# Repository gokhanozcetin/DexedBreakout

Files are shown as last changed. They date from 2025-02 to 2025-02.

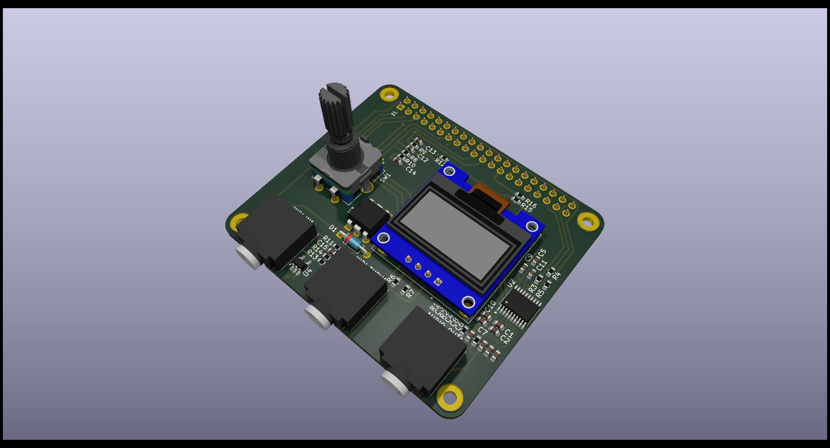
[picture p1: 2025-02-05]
dexedbreakout.png

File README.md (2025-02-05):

DexedBreakout is a small Raspberry Pi Hat that fits into of the shelf RPI cases with small modifications. The connections are aligned to RPI connectors so that the assmebly can be enclosed easily.

It includes a PCM5102 DAC, a 0.96 inch OLED and a rotary encoder. The PCB is arranged so that the OLED centers the Raspberry. It offers TRS type MIDI IN, a true hardware TRS type MIDI THRU and a stereo audio output jack.

The MIDI IN is connected to RX pin of the Raspberry PI I/O. MIDI THRU port replicates the MIDI IN signal via a buffer chip.

PCM5102 is configured to run in I2S mode and configuration pins are hardwired.

The Encoder is KY-040 type encoder. A/CLK is connected to GPIO9, B/DAT is connected to GPIO10 and switch is connected to GPIO11.

The 40 pin I/O header is designed to be a female regular input. A passthrough type would be much nicer to lower the position of the card however neither SMT nor THT pass-through connectors fit since the I/O is very close to the edge. It is possible not to populate the female header and directly solder the card to the RPI to lower the height and fit the assembly in to a case.

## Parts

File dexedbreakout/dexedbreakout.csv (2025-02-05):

Reference | Value | Datasheet | Footprint | Qty | DNP
AUDIO_OUT1;MIDI_IN1;MIDI_THRU1 | AudioJack3_SwitchTR | ~ | Connector_Audio:Jack_3.5mm_CUI_SJ1-3525N_Horizontal | 3
C1;C2;C3;C4;C5;C6;C7 | 2.2u | ~ | Capacitor_SMD:C_0603_1608Metric | 7
C8;C9;C10;C11;C15 | 0.1u | ~ | Capacitor_SMD:C_0603_1608Metric | 5
C12;C13;C14 | 10n | ~ | Capacitor_SMD:C_0603_1608Metric | 3
D1 | 1N4148 | https://assets.nexperia.com/documents/data-sheet/1N4148_1N4448.pdf | Diode_THT:D_DO-35_SOD27_P7.62mm_Horizontal | 1
J1 | Raspberry_Pi_2_3 | https://www.raspberrypi.org/documentation/hardware/raspberrypi/schematics/rpi_SCH_3bplus_1p0_reduced.pdf | Connector_PinSocket_2.54mm:PinSocket_2x20_P2.54mm_Vertical | 1
R1;R2;R12 | 470 | ~ | Resistor_SMD:R_0603_1608Metric | 3
R3;R4;R5 | 22 | ~ | Resistor_SMD:R_0603_1608Metric | 3
R6;R7;R8;R9;R10 | 4k7 | ~ | Resistor_SMD:R_0603_1608Metric | 5
R11;R13;R14 | 220 | ~ | Resistor_SMD:R_0603_1608Metric | 3
R15;R16 | 0 | ~ | Resistor_SMD:R_0603_1608Metric | 2
SW1 | RotaryEncoder_Switch | ~ | Rotary_Encoder:RotaryEncoder_Alps_EC11E-Switch_Vertical_H20mm_CircularMountingHoles | 1
U1 | DM-OLED096-636 |  | DM-OLED096-636:MODULE_DM-OLED096-636 | 1
U2 | PCM5102A | https://www.ti.com/lit/ds/symlink/pcm5102a.pdf | Package_SO:TSSOP-20_4.4x6.5mm_P0.65mm | 1
U3 | 4N35 | https://www.vishay.com/docs/81181/4n35.pdf | Package_DIP:DIP-6_W7.62mm | 1
U4 | 74LVC1G17 | https://www.ti.com/lit/ds/symlink/sn74lvc1g17.pdf | Package_TO_SOT_SMD:SOT-23-5_HandSoldering | 1

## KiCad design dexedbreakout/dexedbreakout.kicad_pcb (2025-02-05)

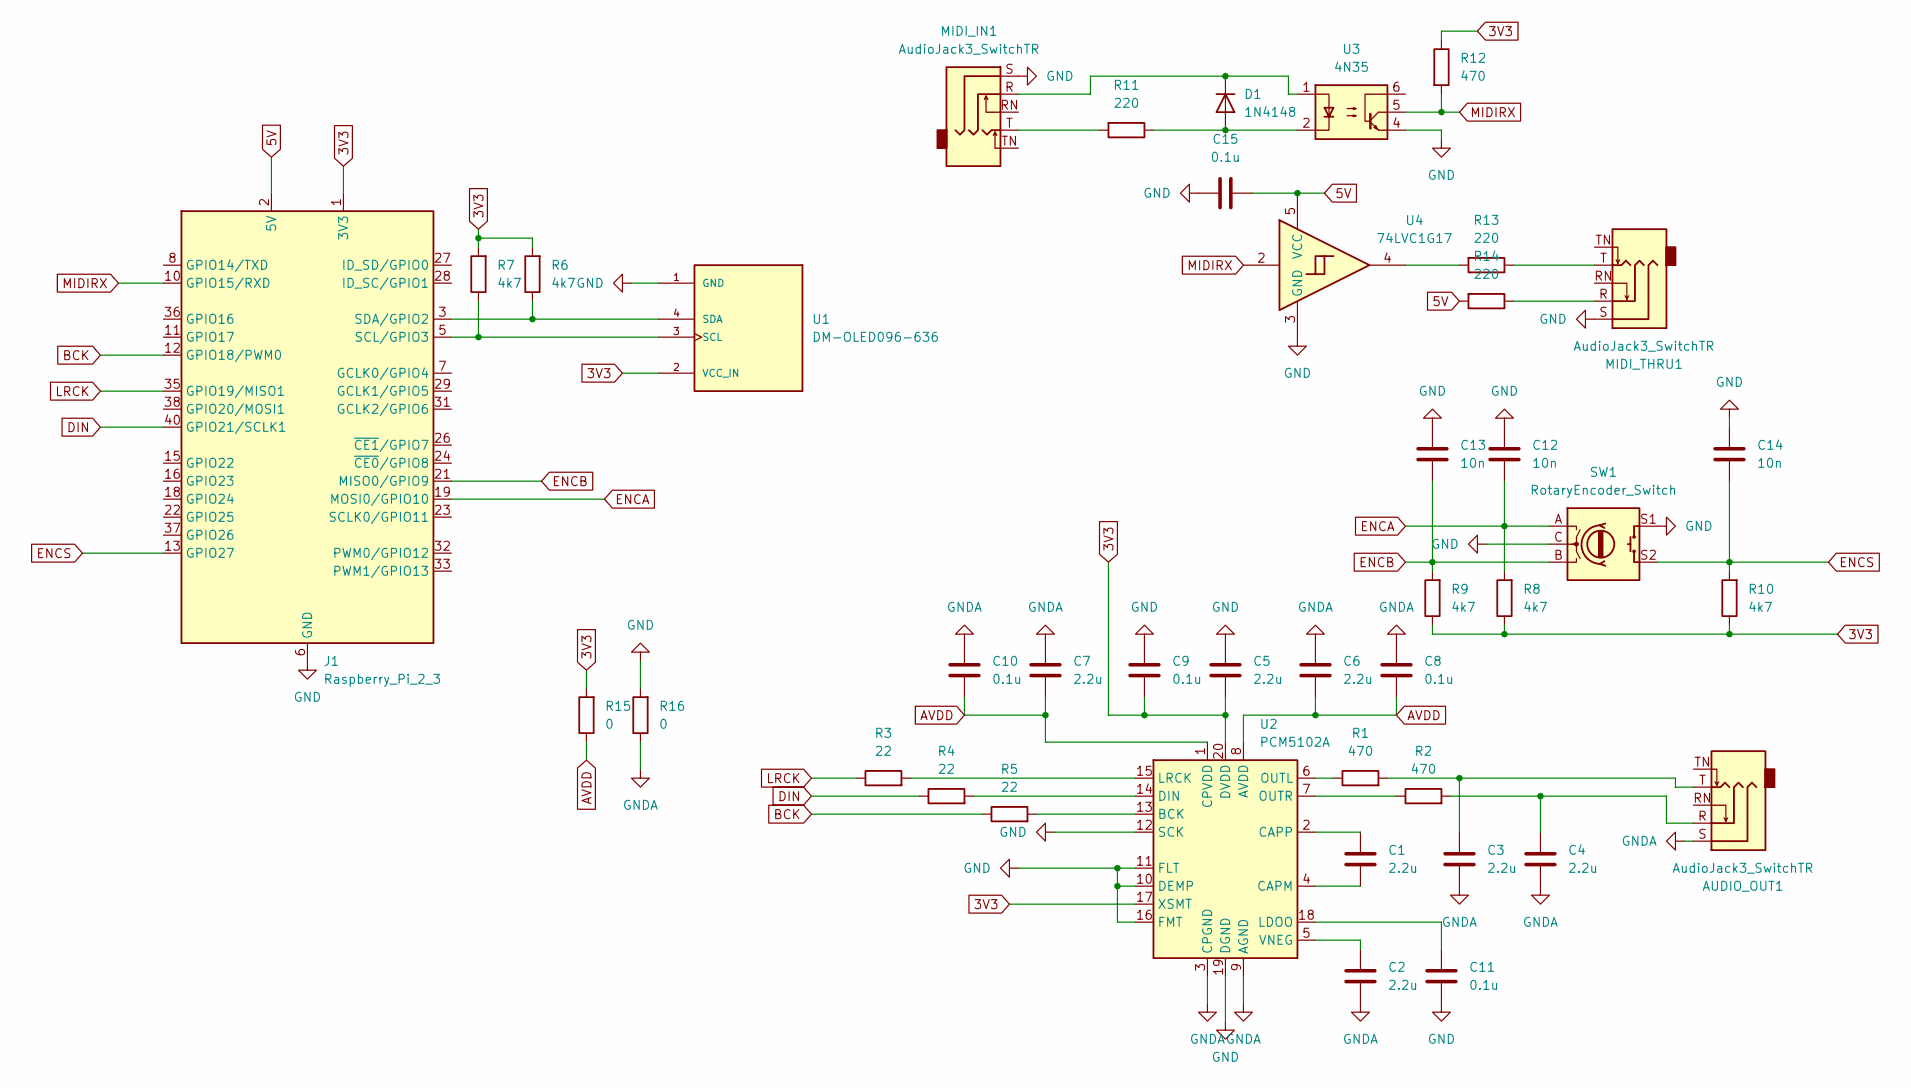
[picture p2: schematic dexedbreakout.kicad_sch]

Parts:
AUDIO_OUT1: AudioJack3_SwitchTR; Jack_3.5mm_CUI_SJ1-3525N_Horizontal
C1, C2, C3, C4, C5, C6, C7: 2.2u; C_0603_1608Metric
C8, C9, C10, C11, C15: 0.1u; C_0603_1608Metric
C12, C13, C14: 10n; C_0603_1608Metric
D1: 1N4148; D_DO-35_SOD27_P7.62mm_Horizontal
J1: Raspberry_Pi_2_3; PinSocket_2x20_P2.54mm_Vertical
MIDI_IN1: AudioJack3_SwitchTR; Jack_3.5mm_CUI_SJ1-3525N_Horizontal
MIDI_THRU1: AudioJack3_SwitchTR; Jack_3.5mm_CUI_SJ1-3525N_Horizontal
R1, R2, R12: 470; R_0603_1608Metric
R3, R4, R5: 22; R_0603_1608Metric
R6, R7, R8, R9, R10: 4k7; R_0603_1608Metric
R11, R13, R14: 220; R_0603_1608Metric
R15, R16: 0; R_0603_1608Metric
SW1: RotaryEncoder_Switch; RotaryEncoder_Alps_EC11E-Switch_Vertical_H20mm_CircularMoun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
U1: DM-OLED096-636; MODULE_DM-OLED096-636; PARTREV 2018-09-10
U2: PCM5102A; TSSOP-20_4.4x6.5mm_P0.65mm
U3: 4N35; DIP-6_W7.62mm
U4: 74LVC1G17; SOT-23-5_HandSoldering

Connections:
3V3: C5.2, C9.2, J1.1 (3V3), J1.17 (3V3), R6.2, R7.2, R8.1, R9.1, R10.1, R12.1, R15.2, U1.2 (VCC_IN), U2.17 (XSMT), U2.20 (DVDD)
5V: C15.2, J1.2 (5V), J1.4 (5V), R14.2, U4.5 (VCC)
AVDD: C6.2, C7.2, C8.2, C10.2, R15.1, U2.1 (CPVDD), U2.8 (AVDD)
BCK: J1.12 (GPIO18/PWM0), R5.1
DIN: J1.40 (GPIO21/SCLK1), R4.1
ENCA: C12.2, J1.19 (MOSI0/GPIO10), R8.2, SW1.A
ENCB: C13.2, J1.21 (MISO0/GPIO9), R9.2, SW1.B
ENCS: C14.2, J1.13 (GPIO27), R10.2, SW1.S2
GND: C5.1, C9.1, C11.2, C12.1, C13.1, C14.1, C15.1, J1.6 (GND), J1.9 (GND), J1.14 (GND), J1.20 (GND), J1.25 (GND), J1.30 (GND), J1.34 (GND), J1.39 (GND), MIDI_IN1.S, MIDI_THRU1.S, R16.2, SW1.C, SW1.S1, U1.1 (GND), U2.10 (DEMP), U2.11 (FLT), U2.12 (SCK), U2.16 (FMT), U2.19 (DGND), U3.4, U4.3 (GND)
GNDA: AUDIO_OUT1.S, C2.2, C3.2, C4.2, C6.1, C7.1, C8.1, C10.1, R16.1, U2.3 (CPGND), U2.9 (AGND)
LRCK: J1.35 (GPIO19/MISO1), R3.1
MIDIRX: J1.10 (GPIO15/RXD), R12.2, U3.5, U4.2
unnamed: AUDIO_OUT1.R, C4.1, R2.2
unnamed: AUDIO_OUT1.T, C3.1, R1.2
unnamed: D1.2 (A), R11.1, U3.2
unnamed: D1.1 (K), MIDI_IN1.R, U3.1
unnamed: J1.5 (SCL/GPIO3), R7.1, U1.3 (SCL)
unnamed: J1.3 (SDA/GPIO2), R6.1, U1.4 (SDA)
unnamed: MIDI_IN1.T, R11.2
unnamed: MIDI_THRU1.R, R14.1
unnamed: MIDI_THRU1.T, R13.1
unnamed: R13.2, U4.4
unnamed: R5.2, U2.13 (BCK)
unnamed: C1.2, U2.4 (CAPM)
unnamed: C1.1, U2.2 (CAPP)
unnamed: R4.2, U2.14 (DIN)
unnamed: C11.1, U2.18 (LDOO)
unnamed: R3.2, U2.15 (LRCK)
unnamed: R1.1, U2.6 (OUTL)
unnamed: R2.1, U2.7 (OUTR)
unnamed: C2.1, U2.5 (VNEG)

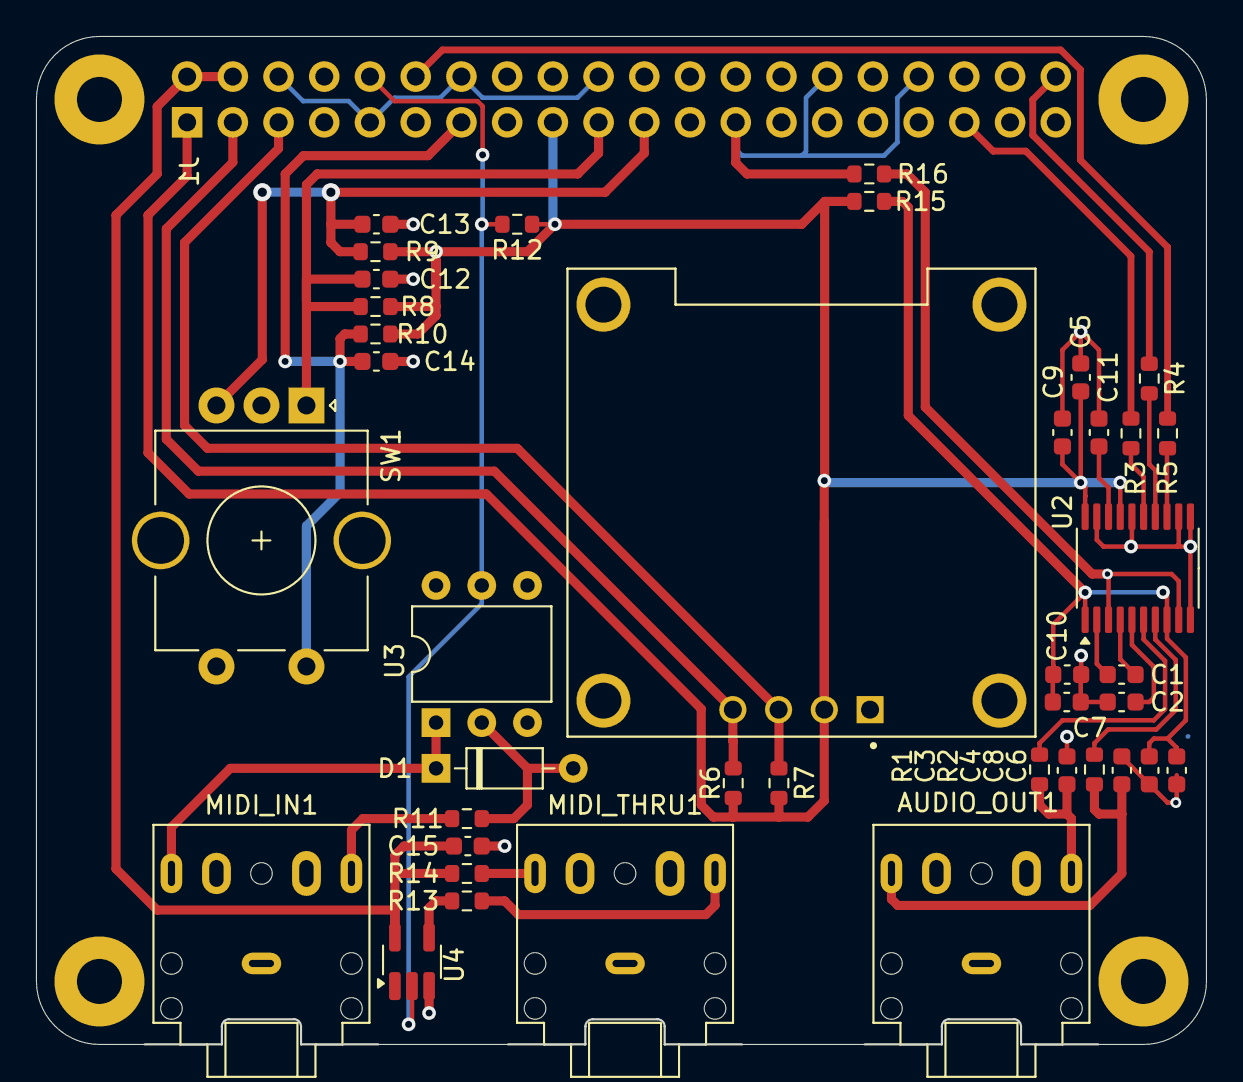
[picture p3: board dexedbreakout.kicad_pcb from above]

Board: 2 copper layers, 65.0 x 56.0 mm, 41 parts (1 on the bottom side), 31 nets.
